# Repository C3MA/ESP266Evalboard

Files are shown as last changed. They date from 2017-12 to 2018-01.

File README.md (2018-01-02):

# ESP8266Evalboard

The purpose of this project is to provide open source based home automation inspiration. It consists of one or more ESP8266 evaluation boards with sensors and actors which connect to a raspberry pi with openhab.

For further documentation, look up the Docu folder in this repository.

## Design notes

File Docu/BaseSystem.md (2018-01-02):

# Base System

The raspberry will open an access point.

## Hardware
Prequirements are :
* Raspberry Pi 3
* Raspberry Pi 2 with Wifi Dongle.

each version must be installed with **raspbian** a *debian* based operation system for these hardware.

## Software

Always it is a good idea to update the packages sources:
`sudo apt update`   

### Wifi
The wifi is realized with the service *hostapd*.

The configuration is done with the following configuration file */etc/hostapd/hostapd.conf*.
The example configuration looks like the following:
`interface=wlan0`   
``   
`ssid=WLAN1`   
`channel=1`   
`hw_mode=g`   
`ieee80211n=1`   
`ieee80211d=1`   
`country_code=DE`   
`wmm_enabled=1`   
``   
``   
`auth_algs=1`   
`wpa=2`   
`wpa_key_mgmt=WPA-PSK`   
`rsn_pairwise=CCMP`   
`wpa_passphrase=c3ma_123`   

### DHCP Server
In order, that each device in the new wifi gets an IP address, there is a DHCP server.
It is configured with the following steps:
After installing *dnsmasq*, its configuration is done in the file */etc/dnsmasq.conf*.
The example configuration looks like this:

`interface=wlan0`   
`dhcp-range=192.168.1.100,192.168.1.150,24h`   
`dhcp-option=option:dns-server,192.168.1.1`   

### Activation
In order to use the new settings the easiest way is to reboot the device:
`sudo reboot`   

## Communication Server
The communication between the devices is realized with the MQTT protocol.
Therefor a MQTT Server must be installed on the raspberry.

It was used **moqquitto**.

The package must be installed:
`sudo apt install mosquitto`   

And no configuration is necessary.

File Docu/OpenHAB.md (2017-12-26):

# OpenHAB
Is a homeautomation project, called **open Home Automation Bus** (<http://openhab.org>) with the focus provide a central plattform where different sensors and actors can be connected 
## Installation
Prequirements are :
* Raspberry Pi 3
* Raspberry Pi 2 with Wifi Dongle.

each version must be installed with **raspbian** a *debian* based operation system for these hardware. 

OpenHABian is a tiny terminal command line tool, that installs all dependencies. In order to install it, the following commands must be executed:

`cd /opt/`   
`sudo git clone https://github.com/openhab/openhabian.git`   
`sudo ln -s /opt/openhabian/openhabian-setup.sh /usr/local/bin/openhabian-config`   

The program can now be executed from the commandline:

`sudo openhabian-config`

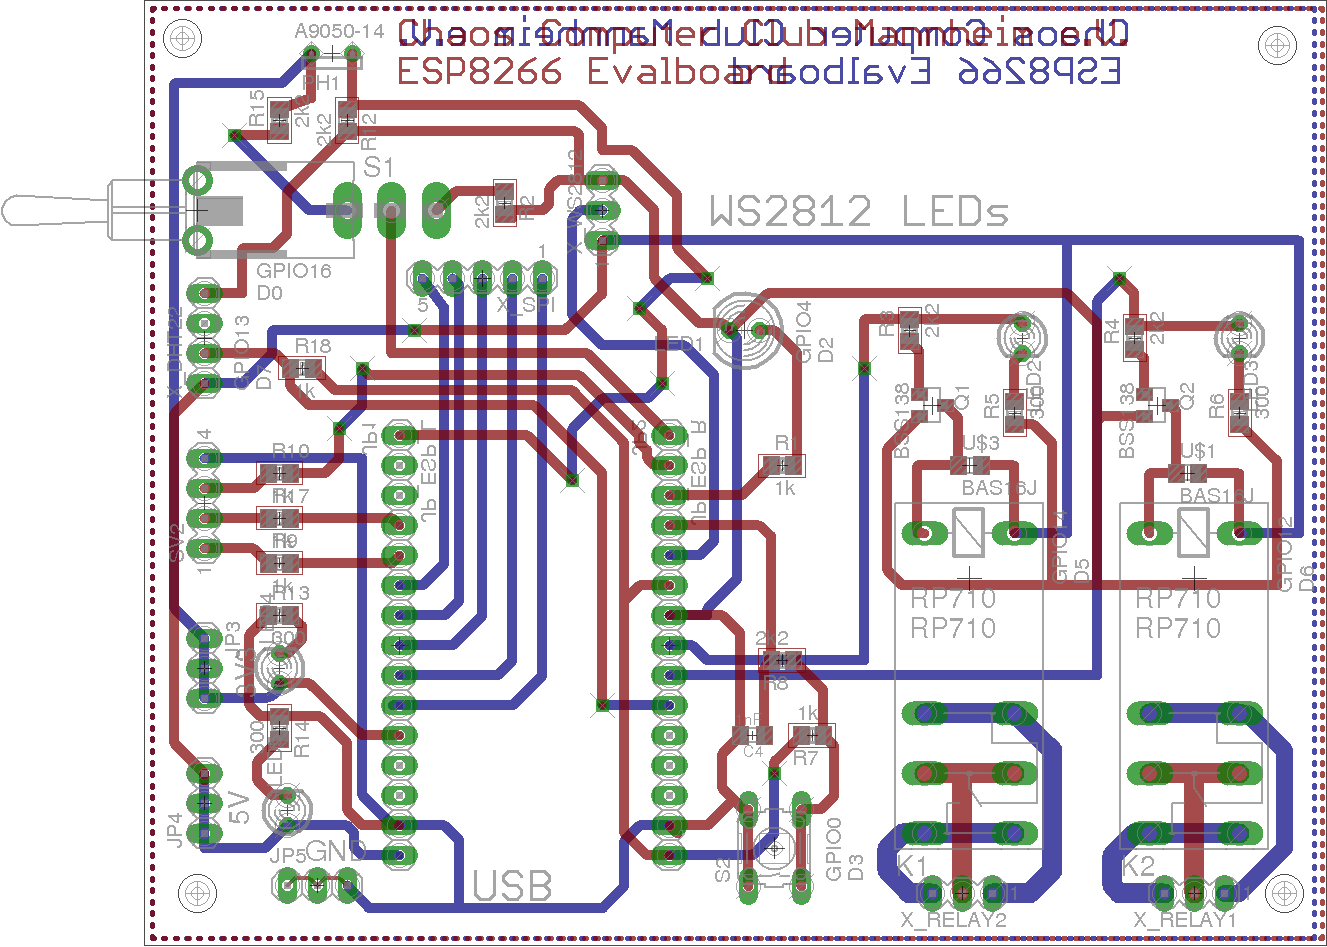
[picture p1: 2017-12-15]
Board/ESPSensorBoard_brd.png

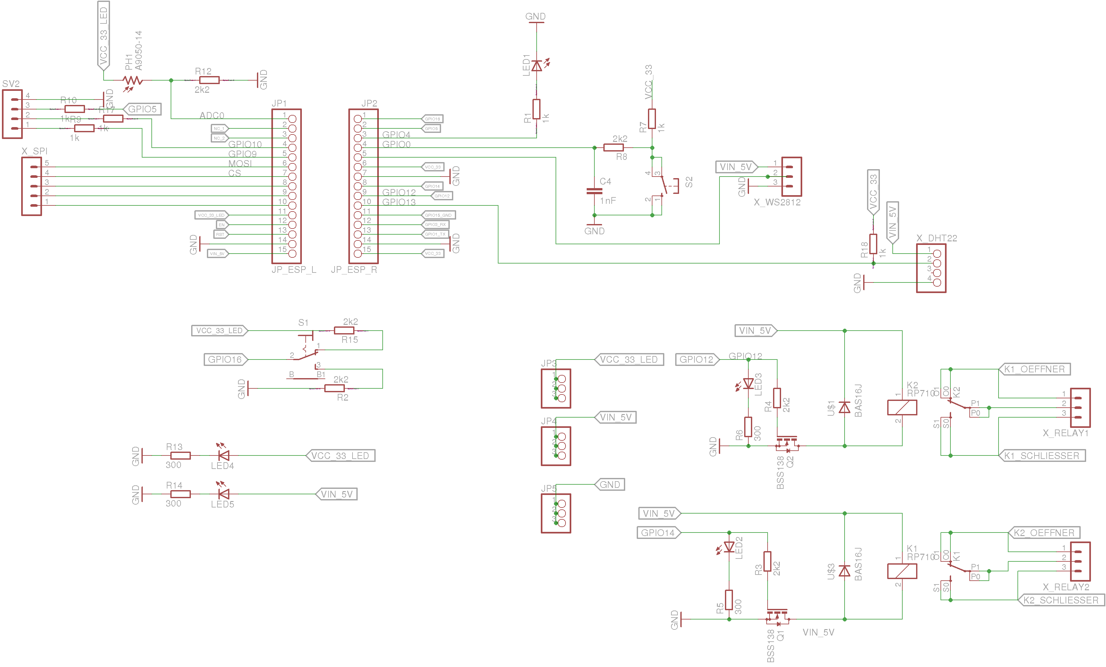
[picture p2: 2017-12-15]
Board/ESPSensorBoard_sch.png

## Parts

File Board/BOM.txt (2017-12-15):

Partlist

Exported from ESPSensorBoard.sch at 12.07.17 18:20

EAGLE Version 6.6.0 Copyright (c) 1988-2014 CadSoft

Assembly variant: 

Part     Value          Device     Package  Library                 Sheet

C4       1nF            C-EUC0805K C0805K   rcl                     1
JP1      JP_ESP_L       PINHD-1X15 1X15     pinhead                 1
JP2      JP_ESP_R       PINHD-1X15 1X15     pinhead                 1
JP3                     PINHD-1X3  1X03     pinhead                 1
JP4                     PINHD-1X3  1X03     pinhead                 1
JP5                     PINHD-1X3  1X03     pinhead                 1
K1       RP710          RP710      RP710    relay                   1
K2       RP710          RP710      RP710    relay                   1
LED1                    LED5MM     LED5MM   led                     1
LED2                    LED3MM     LED3MM   led                     1
LED3                    LED3MM     LED3MM   led                     1
LED4                    LED3MM     LED3MM   led                     1
LED5                    LED3MM     LED3MM   led                     1
PH1      A9050-14       M9960_11A  M9960    photo-elements          1
Q1       BSS138         BSS123     SOT23    transistor-small-signal 1
Q2       BSS138         BSS123     SOT23    transistor-small-signal 1
R1       1k             R          R0805    eagle-ltspice           1
R2       2k2            R          R0805    eagle-ltspice           1
R3       2k2            R-EU_R0805 R0805    rcl                     1
R4       2k2            R-EU_R0805 R0805    rcl                     1
R5       300            R-EU_R0805 R0805    rcl                     1
R6       300            R-EU_R0805 R0805    rcl                     1
R7       1k             R-EU_R0805 R0805    rcl                     1
R8       2k2            R-EU_R0805 R0805    rcl                     1
R9       1k             R          R0805    eagle-ltspice           1
R10      1k             R          R0805    eagle-ltspice           1
R12      2k2            R          R0805    eagle-ltspice           1
R13      300            R-EU_R0805 R0805    rcl                     1
R14      300            R-EU_R0805 R0805    rcl                     1
R15      2k2            R          R0805    eagle-ltspice           1
R17      1k             R          R0805    eagle-ltspice           1
R18      1k             R          R0805    eagle-ltspice           1
S1                      LPV-1      LPV-1    switchmodified          1
S2                      10-XX      B3F-10XX switch-omron            1
SV2                     MA04-1     MA04-1   con-lstb                1
U$1      BAS16J         BAS16J     0805-POL thomas2012              1
U$3      BAS16J         BAS16J     0805-POL thomas2012              1
X_DHT22                 PINHD-1X4  1X04     pinhead                 1
X_RELAY1                MA03-1     MA03-1   con-lstb                1
X_RELAY2                MA03-1     MA03-1   con-lstb                1
X_SPI                   MA05-1     MA05-1   con-lstb                1
X_WS2812                MA03-1     MA03-1   con-lstb                1

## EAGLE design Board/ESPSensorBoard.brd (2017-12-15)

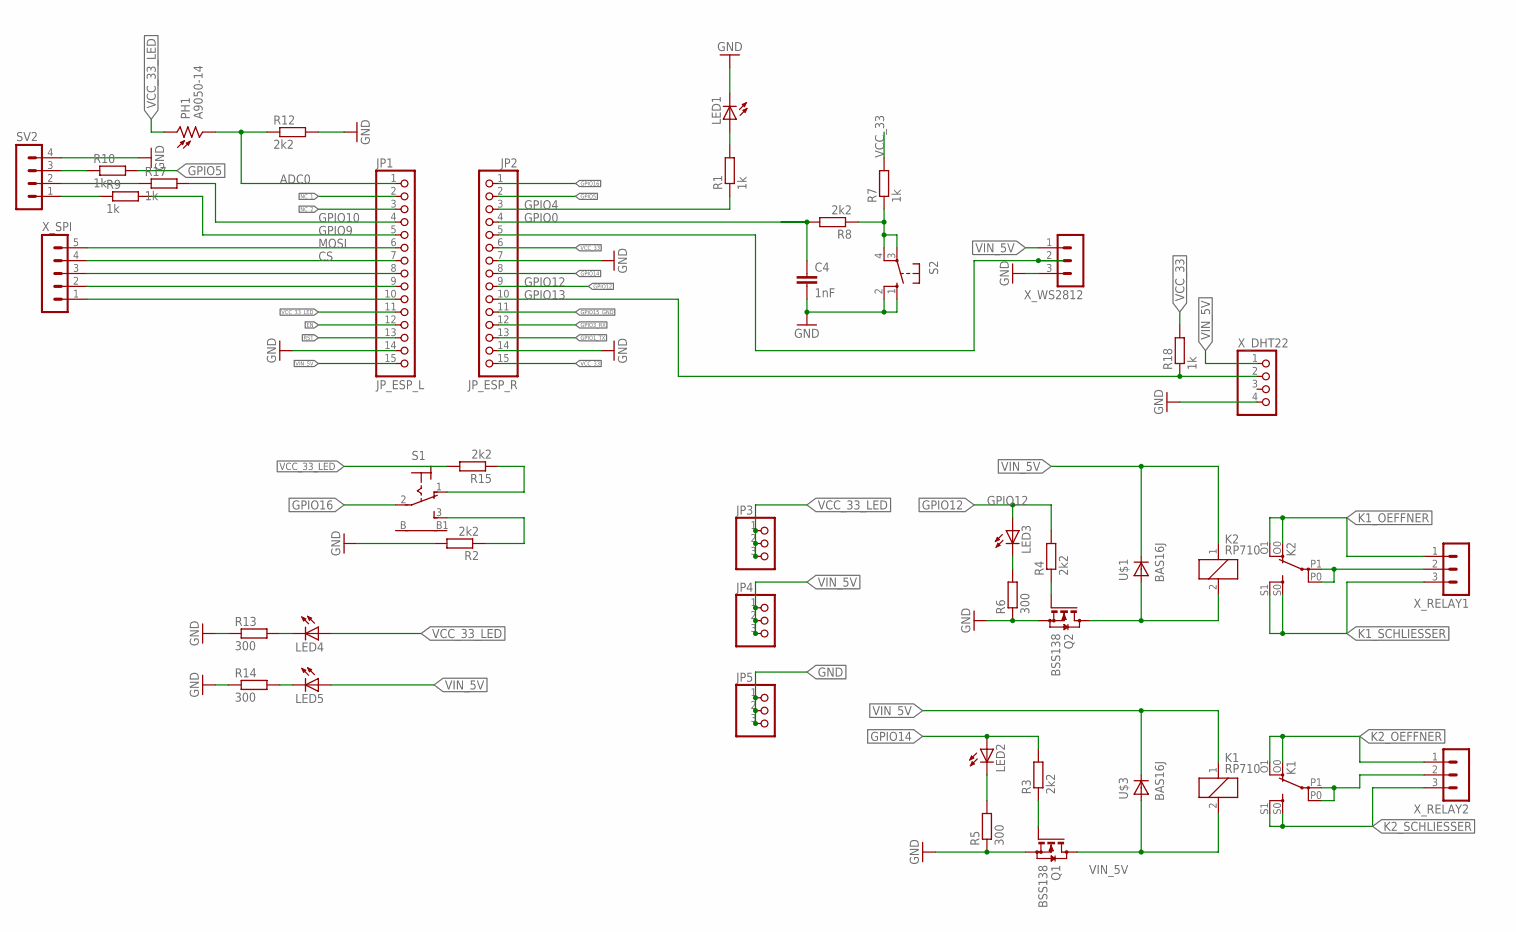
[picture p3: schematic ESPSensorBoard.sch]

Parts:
C4: 1nF; C0805K
JP1: JP_ESP_L; 1X15
JP2: JP_ESP_R; 1X15
JP3, JP4, JP5: PINHD-1X3; 1X03
K1, K2: RP710
LED1: LED5MM
LED2, LED3, LED4, LED5: LED3MM
PH1: A9050-14; M9960
Q1, Q2: BSS138; SOT23
R1, R7, R9, R10, R17, R18: 1k; R0805
R2, R3, R4, R8, R12, R15: 2k2; R0805
R5, R6, R13, R14: 300; R0805
S1: LPV-1
S2: 10-XX; B3F-10XX
SV2: MA04-1
U$1, U$3: BAS16J; 0805-POL
X_DHT22: PINHD-1X4; 1X04
X_RELAY1, X_RELAY2: MA03-1
X_SPI: MA05-1
X_WS2812: MA03-1

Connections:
ADC0: JP1.1, PH1.2, R12.1
CS: JP1.7, X_SPI.4
EN: JP1.12
GND: C4.2, JP1.14, JP2.7, JP2.14, JP5.1, JP5.2, JP5.3, LED1.K (C), Q1.2 (S), Q2.2 (S), R2.2, R5.1, R6.1, R12.2, R13.1, R14.1, S2.1 (S), S2.2 (S1), SV2.4, X_DHT22.4, X_WS2812.3
GPIO0: C4.1, JP2.4, R8.2
GPIO1_TX: JP2.13
GPIO2: JP2.5, X_WS2812.2
GPIO3_RX: JP2.12
GPIO4: JP2.3, R1.1
GPIO5: JP2.2, R10.2
GPIO9: JP1.5, R9.2
GPIO10: JP1.4, R17.2
GPIO12: JP2.9, LED3.A, R4.2
GPIO13: JP2.10, R18.1, X_DHT22.2
GPIO14: JP2.8, LED2.A, R3.2
GPIO15_GND: JP2.11
GPIO16: JP2.1, S1.2
K1_OEFFNER: K2.O0 (O), K2.O1 (O), X_RELAY1.1
K1_SCHLIESSER: K2.S0 (S), K2.S1 (S), X_RELAY1.3
K2_OEFFNER: K1.O0 (O), K1.O1 (O), X_RELAY2.1
K2_SCHLIESSER: K1.S0 (S), K1.S1 (S), X_RELAY2.3
MOSI: JP1.6, X_SPI.5
unnamed: R2.1, S1.3 (S)
unnamed: Q2.1 (G), R4.1
unnamed: LED1.A, R1.2
unnamed: Q1.1 (G), R3.1
unnamed: R9.1, SV2.1
unnamed: R10.1, SV2.3
unnamed: K1.P0, K1.P1, X_RELAY2.2
unnamed: K1.2, Q1.3 (D), U$3.A
unnamed: LED4.K (C), R13.2
unnamed: JP1.8, X_SPI.3
unnamed: K2.P0, K2.P1, X_RELAY1.2
unnamed: K2.2, Q2.3 (D), U$1.A
unnamed: LED2.K (C), R5.2
unnamed: LED3.K (C), R6.2
unnamed: R7.1, R8.1, S2.3, S2.4 (P1)
unnamed: LED5.K (C), R14.2
unnamed: JP1.9, X_SPI.2
unnamed: JP1.10, X_SPI.1
unnamed: R17.1, SV2.2
unnamed: R15.1, S1.1 (O)
NC_1: JP1.2
NC_2: JP1.3
RST: JP1.13
VCC_33: JP2.6, JP2.15, R7.2, R18.2
VCC_33_LED: JP1.11, JP3.1, JP3.2, JP3.3, LED4.A, PH1.1, R15.2
VIN_5V: JP1.15, JP4.1, JP4.2, JP4.3, K1.1, K2.1, LED5.A, U$1.K (C), U$3.K (C), X_DHT22.1, X_WS2812.1

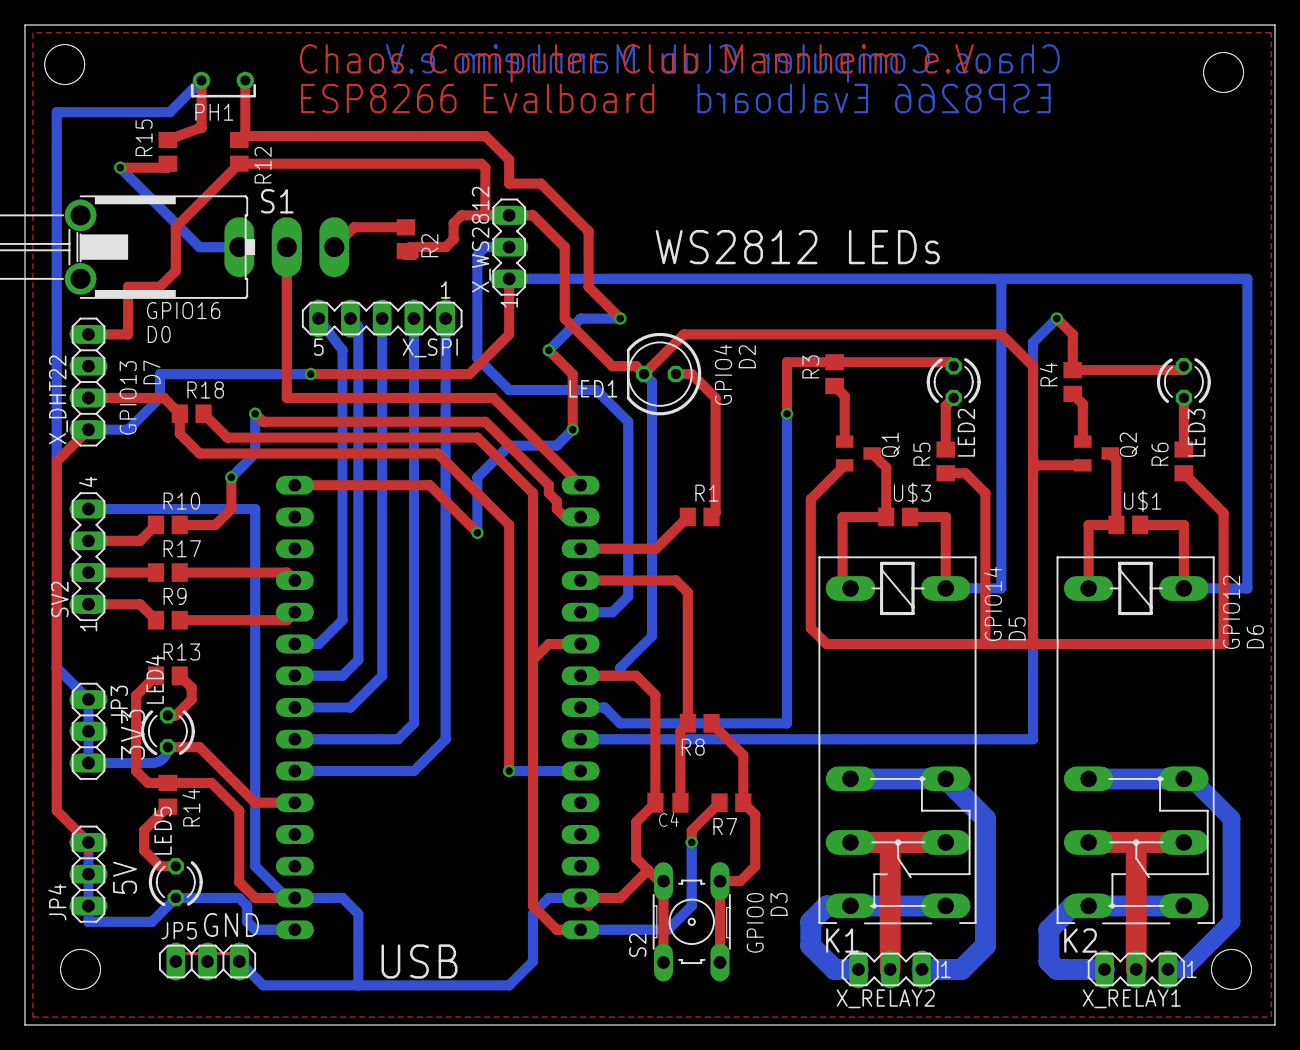
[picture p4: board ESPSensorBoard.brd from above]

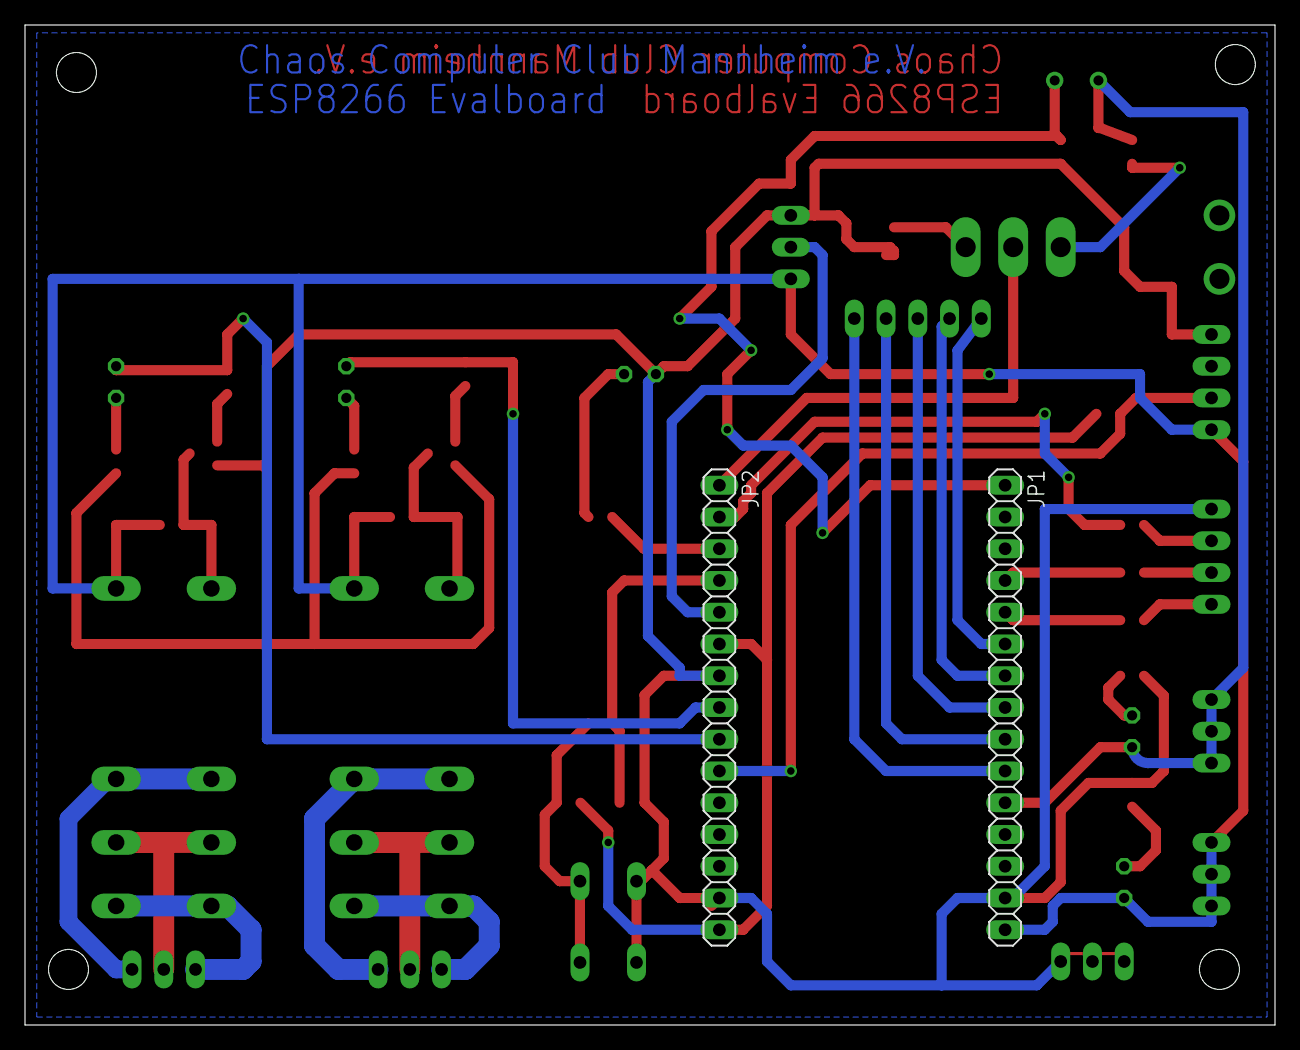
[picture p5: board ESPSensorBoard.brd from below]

Board: 2 copper layers, 100.0 x 80.0 mm, 42 parts (2 on the bottom side), 41 nets.

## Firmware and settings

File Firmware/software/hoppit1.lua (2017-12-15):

-- HoppIT Test
gpio.mode(2, gpio.OUTPUT,gpio.PULLUP) -- GPIO4
gpio.mode(6, gpio.OUTPUT, gpio.PULLUP) -- GPIO12
gpio.mode(5, gpio.OUTPUT, gpio.PULLUP) -- GPIO14
gpio.write(2, gpio.LOW)
gpio.write(6, gpio.LOW)
gpio.write(5, gpio.LOW)

gpio.write(2, gpio.HIGH)
gpio.write(6, gpio.HIGH)
gpio.write(5, gpio.HIGH)
print("LED test done")
gpio.write(5, gpio.LOW)

gpio.mode(0, gpio.INPUT)
gpio.mode(3, gpio.INPUT)
tmr.alarm(0, 500, tmr.ALARM_AUTO, function()
    print("Button: at GPIO0  " .. gpio.read(3))
    print("Switch: at GPIO16 " .. gpio.read(0))
    print("Analog: at ADC    " .. adc.read(0) )
    -- Button to LED
    gpio.write(2, gpio.read(3))
    -- Switch to relais
    gpio.write(6, gpio.read(0))
    gpio.write(5, gpio.read(0))

    rgbTemp=0
    rgbHumi=0
    -- Read Temperature and Humidity
    status, temp, humi, temp_dec, humi_dec = dht.read(7) -- GPIO13
    if status == dht.OK then
        -- Integer firmware using this example
        print(string.format("DHT Temperature:%d.%03d;Humidity:%d.%03d\r\n",
              math.floor(temp),
              temp_dec,
              math.floor(humi),
              humi_dec
        ))
    
        -- Float firmware using this example
        rgbTemp=math.floor((temp-25)*15) -- Start with 20 degree
        rgbTemp=math.min(255, math.max(rgbTemp, 0))
        rgbHumi=math.min(255, math.max(math.floor((humi)/5), 0))

        
        print("DHT Temperature:"..temp..";".."Humidity:"..humi .." RGB Temp value: " .. rgbTemp .. " RGB Hmidity: " .. rgbHumi)
        
    elseif status == dht.ERROR_CHECKSUM then
        print( "DHT Checksum error." )
    elseif status == dht.ERROR_TIMEOUT then
        print( "DHT timed out." )
    end
    -- Set the color LEDs
    
    ws2812.write(string.char(adc.read(0)/10, 0, 0) .. string.char(0, rgbTemp, 0) .. string.char(0, 0, rgbHumi))
end)
ws2812.init()
ws2812.write(string.char(32, 0, 0) .. string.char(0, 32, 0) .. string.char(0, 0, 32))

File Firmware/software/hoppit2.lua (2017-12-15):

-- Konfiguration
WLAN_SSID="WLAN1"
WLAN_PASSWORT="c3ma_123"

wifi.setmode(wifi.STATION)
wifi.sta.config(WLAN_SSID, WLAN_PASSWORT)

-- HoppIT Test
gpio.mode(2, gpio.OUTPUT,gpio.PULLUP) -- GPIO4
gpio.mode(6, gpio.OUTPUT, gpio.PULLUP) -- GPIO12
gpio.mode(5, gpio.OUTPUT, gpio.PULLUP) -- GPIO14
gpio.write(2, gpio.LOW)
gpio.write(6, gpio.LOW)
gpio.write(5, gpio.LOW)

gpio.write(2, gpio.HIGH)
gpio.write(6, gpio.HIGH)
gpio.write(5, gpio.HIGH)
print("LED test done")
gpio.write(5, gpio.LOW)

gpio.mode(0, gpio.INPUT)
gpio.mode(3, gpio.INPUT)

-- Mqtt
m = mqtt.Client("Client" .. node.chipid(), 120, "user", "pass")

m:on("connect", function()
    m:publish("/test/" .. node.chipid() .. "/ip",wifi.sta.getip(),0,0)
    print("Connected to Wifi")
    m:subscribe("/test/all/led1",0)
    ws2812.write(string.char(32, 0, 0) .. string.char(0, 0, 32) .. string.char(0, 0, 0))
end)

m:on("message", function(conn, topic, data)
   -- skip emtpy messages
   if (data == nil) then
    return
   end
   if (data == "ON") then
      gpio.write(2, gpio.HIGH)
   elseif (data == "OFF") then
      gpio.write(2, gpio.LOW)
   end
end)

local mytimer1 = tmr.create()

tmr.alarm(0, 500, tmr.ALARM_AUTO, function()
    if wifi.sta.status() ~= 5 then
         print("Connecting to AP...")
         gpio.write(2, (gpio.read(2) + 1) % 2)
      else
        ws2812.write(string.char(32, 0, 0) .. string.char(0, 32, 0) .. string.char(0, 0, 32))
        m:connect("192.168.1.1",1883,0)
        tmr.stop(0)
        gpio.write(2, gpio.LOW)
        mytimer1:start()
        ws2812.write(string.char(32, 0, 0) .. string.char(0, 0, 0) .. string.char(0, 0, 0))
    end
end)

mytimer1:register( 500, tmr.ALARM_AUTO, function()
    
    rgbTemp=0
    rgbHumi=0
    -- Read Temperature and Humidity
    status, temp, humi, temp_dec, humi_dec = dht.read(7) -- GPIO13
    if status == dht.OK then
        -- Float firmware using this example
        rgbTemp=math.floor((temp-25)*15) -- Start with 20 degree
        rgbTemp=math.min(255, math.max(rgbTemp, 0))
        rgbHumi=math.min(255, math.max(math.floor((humi)/5), 0))
        
        m:publish("/test/" .. node.chipid() .. "/hmi",humi,0,0)
        m:publish("/test/" .. node.chipid() .. "/temp",temp,0,0)
        
    elseif status == dht.ERROR_CHECKSUM then
        m:publish("/test/" .. node.chipid() .. "/debug","DHT Checksum error.",0,0)
    elseif status == dht.ERROR_TIMEOUT then
        m:publish("/test/" .. node.chipid() .. "/debug","DHT timed out.",0,0)
    end
end)
ws2812.init()
ws2812.write(string.char(0, 0, 0):rep(3))
